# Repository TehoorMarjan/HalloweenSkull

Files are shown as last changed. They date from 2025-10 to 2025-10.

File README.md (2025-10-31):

# 🎃 HalloweenSkull - Animated Skull with Googly Eyes 👁️

An ESP32-powered animated skull featuring expressive googly eyes using 8x8 LED matrices and spooky sound effects. Perfect for creating an immersive, interactive Halloween decoration that watches and talks to visitors!

<p align="center">
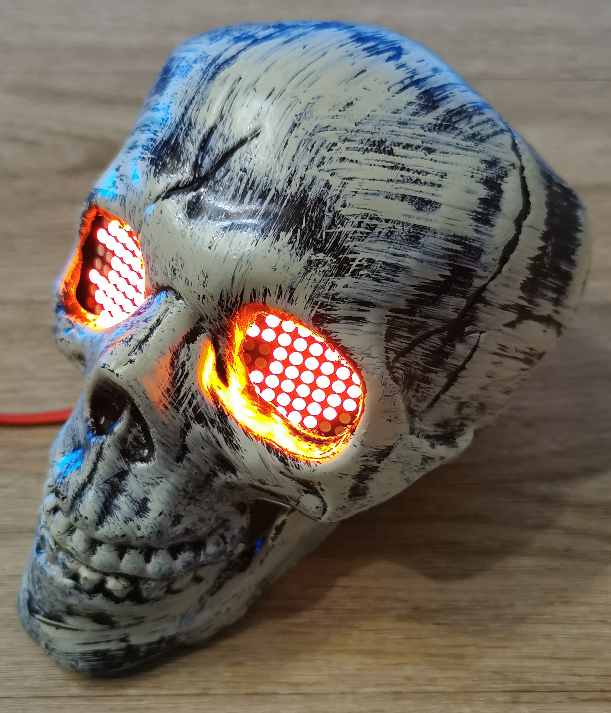
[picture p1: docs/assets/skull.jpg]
Skull Implementation
    
</p>

## 📖 Overview

**HalloweenSkull** brings a decorative skeleton to life with:
- 👀 **Animated LED matrix eyes** with smooth, realistic movements
- 🔊 **Sound effects** including spooky phrases, yawns, and atmospheric sounds
- 🤖 **Autonomous behavior** - the skull randomly looks around, blinks, and speaks
- 🛠️ **Custom 3D-printed mounts** to secure components inside the skull

The project combines hardware, firmware, and mechanical design to create an engaging Halloween decoration that captivates viewers.

👉 **See the README in each folder for detailed component documentation.**

## 🛠️ Hardware Requirements

### Components

- **ESP32 Development Board** (e.g., AZ-Delivery DevKit v4)
- **2x MAX7219 8x8 LED Dot Matrix Modules** (daisy-chained)
- **DFPlayer Mini MP3 Player Module** with microSD card
- **Speaker** (8Ω recommended, connected to DFPlayer)
- **MicroSD Card** (for audio files, FAT32 format)
- **Base Skull**: [5 Pcs Halloween Skeleton Head and Arm Set](https://www.amazon.fr/dp/B0FBW7PP8G)
- **3D Printed Mounts** (STL files in `mechanical/` folder)
- **Power Supply**: 5V, 2A+ recommended
- **Screws and basic hardware** for assembly

### Pin Connections

#### LED Matrices (SPI)
| ESP32 Pin | MAX7219 Pin | Description |
| --- | --- | --- |
| GPIO 18 | CLK | Clock signal |
| GPIO 23 | DIN | Data input (MOSI) |
| GPIO 5 | CS | Chip select |
| 5V | VCC | Power supply |
| GND | GND | Ground |

#### DFPlayer Mini (UART)
| ESP32 Pin | DFPlayer Pin | Description |
| --- | --- | --- |
| GPIO 17 | RX | ESP32 TX2 |
| GPIO 16 | TX | ESP32 RX2 |
| 5V | VCC | Power |
| GND | GND | Ground |

> 💡 The two MAX7219 modules are daisy-chained: Device 0 = Right eye, Device 1 = Left eye

## ✨ Features

### 👁️ Eye Animations
- **Googly eyes** with movable 2x2 pixel irises
- **Smooth interpolated movement** between positions
- **Multiple positions**: center, top, bottom, left, right, diagonals
- **Blinking/closing** animation with configurable probability
- **Adjustable brightness** (0-15)

### 🔊 Sound Effects
Three types of sounds played randomly:
- **Speech sounds** (folder 01) - Spooky phrases and words
- **Yawning sounds** (folder 02) - Triggered when eyes close
- **Effect sounds** (folder 03) - Atmospheric horror effects

Sounds are timed with configurable delays for unpredictable, natural behavior.

### 🎛️ Customization
All behavior is configurable via `firmware/src/config.h`:
- Animation timing and delays
- Eye brightness
- Sound volume and folder assignments
- Blink probability

## 🚀 Getting Started

### 1️⃣ Prepare the SD Card

1. Format a microSD card as **FAT32**
2. Copy the `sounds/` folder structure to the SD card root:
   ```
   SD Card Root/
   ├── 01/  (Speech sounds - 001.mp3, 002.mp3, ...)
   ├── 02/  (Yawning sounds)
   └── 03/  (Effect sounds - YOU MUST ADD THESE)
   ```
3. **Important**: The `03/` folder is empty by default due to licensing. Download your own sound effects from [Pixabay](https://pixabay.com/sound-effects/), [Freesound.org](https://freesound.org/), or similar sites.
4. Name files as `001.mp3`, `002.mp3`, etc. in MP3 format
5. Update `firmware/src/config.h` to match the number of files you added:
   ```cpp
   #define DFPLAYER_CONFIG { \
       .effectNbSounds = 6  // Change this to your file count
   }
   ```

### 2️⃣ 3D Print the Mounts

1. Open `mechanical/Mounts.FCStd` in FreeCAD, or use the exported STL files
2. Print the 3 parts:
   - **SupportLED**: Holds the two LED matrices
   - **HolderTop**: Upper arm part, screws to the skull
   - **HolderBottom**: Lower arm part, screws to SupportLED
3. See [`mechanical/README.md`](mechanical/README.md) for assembly details

### 3️⃣ Build and Upload Firmware

1. **Install PlatformIO** (VS Code extension recommended)
2. **Clone the repository**:
   ```bash
   git clone https://github.com/TehoorMarjan/HalloweenSkull.git
   cd HalloweenSkull/firmware
   ```
3. **Configure** (optional): Edit `src/config.h` for pin changes or customization
4. **Build and upload**:
   ```bash
   pio run --target upload
   ```
5. **Monitor** (optional):
   ```bash
   pio device monitor
   ```

See [`firmware/README.md`](firmware/README.md) for detailed firmware documentation.

### 4️⃣ Hardware Assembly

1. **Mount LED matrices** to the SupportLED using screws
2. **Attach the holder arms** creating an adjustable articulation
3. **Position inside skull**: Screw HolderTop inside the skull's "mouth"
4. **Connect electronics**: Wire ESP32 to LED matrices and DFPlayer
5. **Insert SD card** into DFPlayer Mini
6. **Power up** and test!
7. **Adjust positioning** using the articulated holder
8. **Close the skull** and enjoy your creation!

## 🐛 Troubleshooting

**Eyes don't light up:**
- Check SPI wiring (CLK, DATA, CS pins)
- Verify hardware type matches your LED modules
- Try increasing brightness in firmware config

**No sound:**
- Ensure SD card is FAT32 formatted
- Check UART connections (RX/TX are crossed!)
- Verify audio files follow naming convention (001.mp3, 002.mp3...)
- Update sound file count in firmware config to match your files

**Erratic behavior:**
- Use adequate power supply (2A+ recommended)
- Check all ground connections

> 💡 **See component-specific READMEs for detailed troubleshooting and configuration.**

## 🎨 Customization Ideas

- Add motion sensor to trigger reactions when people approach
- Implement WiFi control for remote triggering
- Add more eye animation modes (cross-eyed, silly)
- Synchronize with other Halloween props
- Add LED strip lighting effects
- Create themed sound sequences for different scenarios

## 📚 Documentation

- **[Firmware README](firmware/README.md)** - Detailed firmware documentation, API reference
- **[Mechanical README](mechanical/README.md)** - 3D models, assembly instructions, photos
- **[Sound Effects Guide](sounds/03/README)** - How to find and prepare audio files

## 🤝 Contributing

Contributions are welcome! Feel free to:
- 🐛 Report bugs via GitHub issues
- 💡 Suggest new features or improvements
- 🔧 Submit pull requests
- 📸 Share photos of your build
- 🎵 Contribute sound effect recommendations

Please ensure your code follows the existing style and includes appropriate documentation.

## � License

This project is licensed under the MIT License - see the [LICENSE](LICENSE) file for details.

### Third-Party Content

- **MAX7219 LED Matrix 3D Model**: By FabroLabs Technologies ([GrabCAD](https://grabcad.com/library/max7219-8x8-led-dot-matrix-display-module-1))
- **Sound Effects**: Not included - users must provide their own from free sources like Pixabay, Freesound.org, etc.

## 🙏 Acknowledgments

- MD_MAX72XX library by MajicDesigns
- DFRobotDFPlayerMini library
- PlatformIO and Arduino communities
- All the amazing free sound effect libraries

## 💀 Happy Halloween! 🎃👻

---

*Built with ❤️ for Halloween 2025 - May your decorations be spooky and your code bug-free!*

**⭐ If you build this project, please star the repo and share photos of your creation!**

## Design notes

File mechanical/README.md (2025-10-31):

# 🎃 HalloweenSkull Mechanical Components 🦴

Welcome to the mechanical folder for the **HalloweenSkull** project! Here you'll
find all the 3D models, CAD files, and documentation needed to build and
customize the mechanical parts of your animated skull.

## 🛠️ Mounts

- **File:** `Mounts.FCStd`
- **Description:** FreeCAD design for the mounts. The mount is split into 3
  bodies for easier print, assembly, and tweaking:
  - **SupportLED:** Holds the two LED matrices (with MAX7219 boards), which are
    screwed onto it.
  - **Holder (2 parts):** A two-part arm linking the support to the plastic
    skull. One part is screwed inside the skull's "mouth", the other to the
    support. The articulation between them allows for position adjustment within
    the skull.

<div align="center">
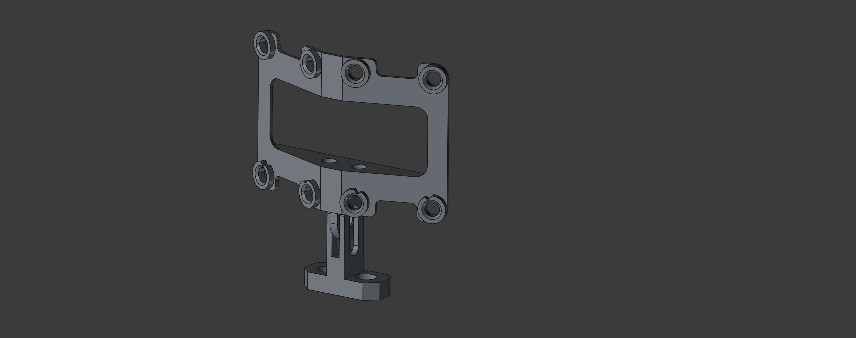
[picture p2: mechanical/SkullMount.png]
Mounts 3D Model
	
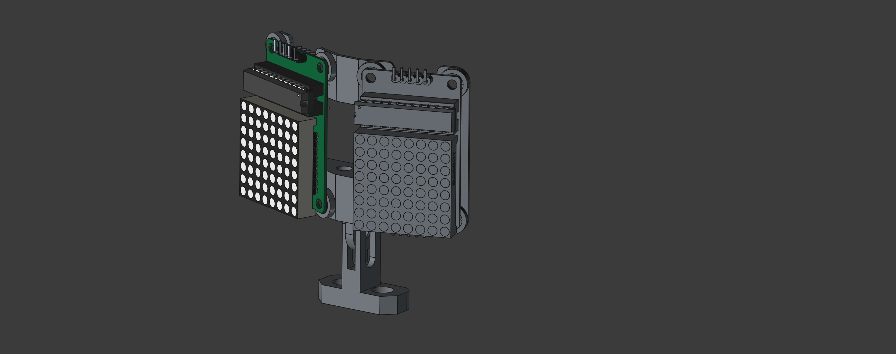
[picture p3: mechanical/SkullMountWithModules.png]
Mounts with Modules
	
</div>

## MAX7219 8x8 LED Dot Matrix Display Module

- **File:** `MAX7219 8x8 LED Dot Matrix Display Module.STEP`
- **Description:** 3D model of the LED matrix display used for the eyes.
- **License:** See
  [`MAX7219 8x8 LED Dot Matrix Display Module.STEP.LICENSE`](MAX7219%208x8%20LED%20Dot%20Matrix%20Display%20Module.STEP.LICENSE)
  for third-party info. Model by FabroLabs Technologies
  ([GrabCAD link](https://grabcad.com/library/max7219-8x8-led-dot-matrix-display-module-1)).

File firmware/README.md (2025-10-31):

# 👁️ HalloweenSkull Firmware 🎃

Welcome to the **HalloweenSkull** firmware! This is the embedded software that brings your animated skull to life with expressive googly eyes and spooky sounds.

## 🚀 Overview

This firmware is designed to run on an **ESP32** microcontroller and controls:
- **Two 8x8 LED matrices** (MAX7219-based) for animated googly eyes
- **DFPlayer Mini** audio module for playing sounds from an SD card

The skull autonomously animates its eyes with realistic movements and randomly plays sounds to create an immersive Halloween experience.

## 🛠️ Hardware Requirements

- **ESP32 Development Board** (e.g., AZ-Delivery DevKit v4)
- **2x MAX7219 8x8 LED Dot Matrix Modules** (daisy-chained)
- **DFPlayer Mini MP3 Player Module**
- **MicroSD Card** (for audio files)
- **Speaker** (connected to DFPlayer Mini)
- **Power Supply** (5V recommended)

### 📌 Pin Connections

#### LED Matrices (SPI)
- **CLK** → GPIO 18
- **DATA (MOSI)** → GPIO 23
- **CS** → GPIO 5

#### DFPlayer Mini (UART)
- **RX** (ESP32 TX2) → GPIO 17
- **TX** (ESP32 RX2) → GPIO 16

> You can modify pin assignments in `src/config.h`

## 📁 Project Structure

```
firmware/
├── platformio.ini          # PlatformIO configuration
├── src/
│   ├── main.cpp           # Main program logic
│   └── config.h           # Configuration constants
└── lib/
    ├── Eyes/              # Eye animation library
    │   ├── Eyes.h
    │   └── Eyes.cpp
    └── Sounds/            # Sound playback library
        ├── Sounds.h
        └── Sounds.cpp
```

## 🎨 Features

### Eye Animations
- **Smooth movement** between positions (top, bottom, left, right, center, diagonals)
- **Blinking/closing** animation with configurable probability
- **Interpolation** for natural eye movement
- **Adjustable brightness** (0-15)

### Sound Effects
The firmware plays three types of sounds from the SD card:
- **Yawning sounds** (folder 02) - triggered when eyes close
- **Speech sounds** (folder 01) - random spooky phrases
- **Effect sounds** (folder 03) - atmospheric effects

Sounds are played randomly with configurable delays to keep the experience unpredictable.

## 🔧 Building & Uploading

### Prerequisites
1. Install [PlatformIO](https://platformio.org/install) (VS Code extension recommended)
2. Prepare your SD card with sound files organized in folders:
   - `01/` - Speech sounds (001.mp3, 002.mp3, ...)
   - `02/` - Yawning sounds
   - `03/` - Effect sounds

### Build Commands

```bash
# Build the project
pio run

# Upload to ESP32
pio run --target upload

# Open serial monitor
pio device monitor
```

Or use the PlatformIO buttons in VS Code! 🔘

## 🎃 Customization Ideas

- Add new eye modes (cross-eyed, silly animations)
- Implement motion sensor triggers
- Add remote control via WiFi/Bluetooth
- Create synchronized light effects
- Add more complex sound sequences

## 📜 License

This project is part of the HalloweenSkull repository.

License is MIT. See the main [LICENSE](../LICENSE) file for details.

## 🤝 Contributing

Contributions are welcome! Feel free to:
- Report bugs via GitHub issues
- Submit pull requests with improvements
- Share your customizations and modifications

## 💀 Happy Haunting! 👻

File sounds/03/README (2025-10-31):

# Sound Effects - Folder 03

## ⚠️ Licensing Notice

The sound effects in this folder are sourced from **Pixabay** and are subject to
their content license terms. Due to licensing restrictions, these audio files
**cannot be redistributed** as part of this repository.

## 🎵 For Your Own Use

If you're building this project yourself, you are **free to download and use**
sound effects from Pixabay or other free sound libraries for your personal
Halloween skull project.

### Recommended Free Sound Libraries

1. **[Pixabay](https://pixabay.com/sound-effects/)** - Free for personal and
   commercial use

   - Search terms: "horror", "scary", "creepy", "halloween", "scream", "laugh"

2. **[Freesound.org](https://freesound.org/)** - CC-licensed sound effects

   - Requires attribution for some sounds

3. **[Zapsplat](https://www.zapsplat.com/)** - Free with attribution

   - Large collection of horror/Halloween sounds

4. **[BBC Sound Effects](https://sound-effects.bbcrewind.co.uk/)** - Free for
   personal use
   - High-quality professional recordings

### File Naming Convention

Files must follow the DFPlayer Mini naming convention:

```
03/
├── 001.mp3  (e.g., evil laugh)
├── 002.mp3  (e.g., scream)
├── 003.mp3  (e.g., creepy whisper)
└── 004.mp3  (e.g., chains rattling)
```

**Format Requirements:**

- MP3 or WAV format
- Sample rate: 16kHz-48kHz recommended
- Bitrate: up to 320kbps
- Files numbered with 3 digits (001, 002, 003, etc.)

### Tips for Best Results

- Keep files short (2-10 seconds) for quick impact
- Normalize volume levels across all files
- Test on your actual speaker to ensure clarity
- Consider your skull's acoustic properties (muffled vs. clear)

---

**Note**: Always respect content licenses and terms of use when downloading
sound effects. If unsure, use content explicitly marked as "Public Domain" or
"CC0".

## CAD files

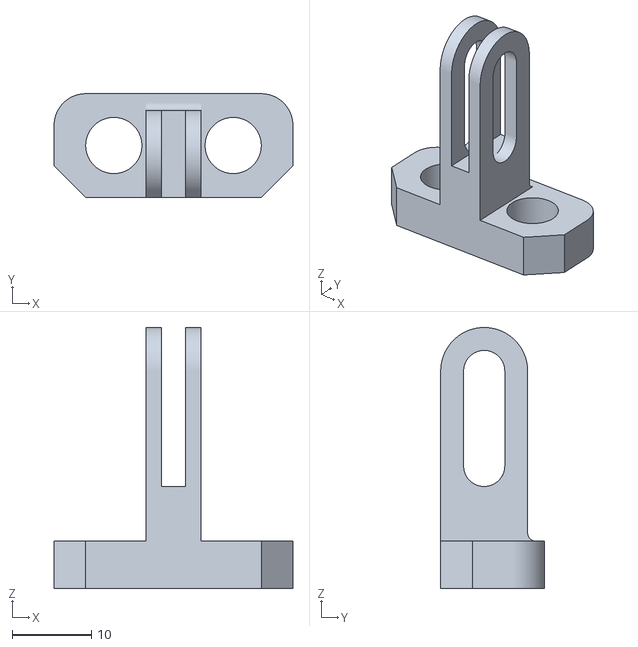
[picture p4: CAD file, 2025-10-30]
mechanical/Mounts-HolderBottom.stl
30.2 x 13.1 x 33.0

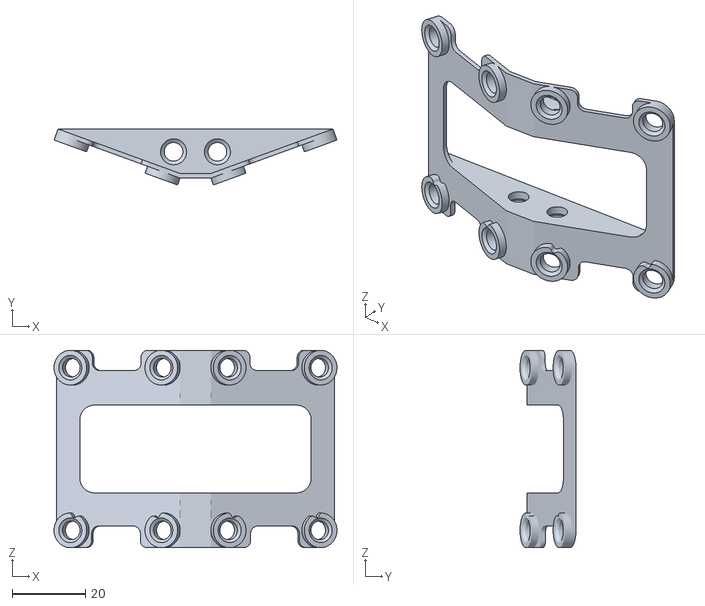
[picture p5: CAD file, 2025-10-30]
mechanical/Mounts-SupportLED.stl
77.4 x 15.3 x 54.0

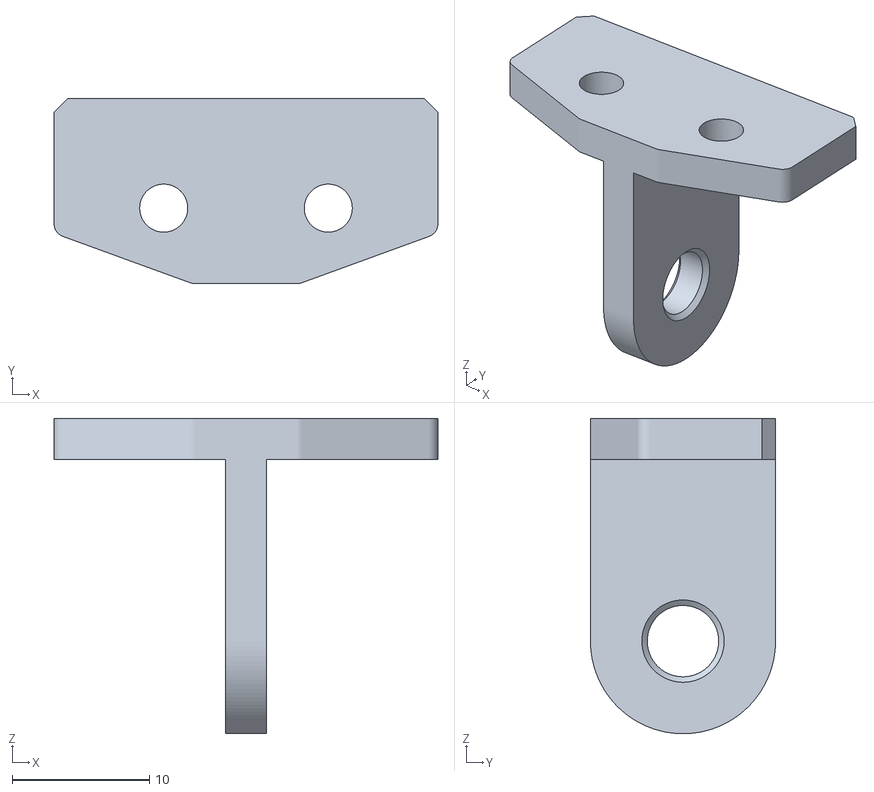
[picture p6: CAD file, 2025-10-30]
mechanical/Mounts-HolderTop.stl
28.0 x 13.5 x 23.0

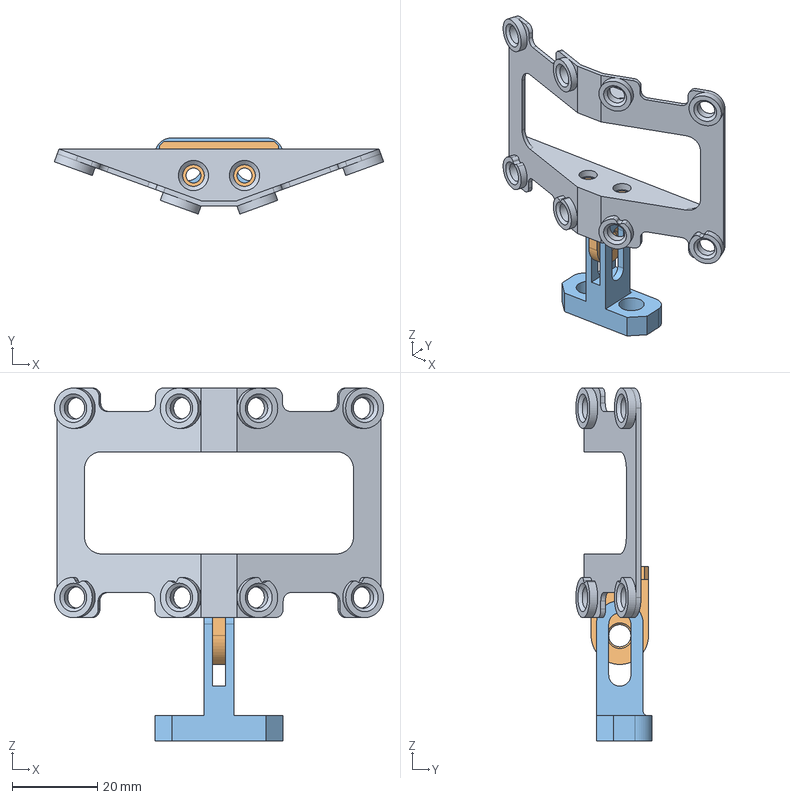
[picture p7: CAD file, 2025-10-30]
mechanical/Mounts.FCStd
77.4 x 17.9 x 83.0 mm
SupportLED
HolderTop
HolderBottom

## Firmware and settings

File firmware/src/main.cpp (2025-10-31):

#include <Arduino.h>
#include <esp_sleep.h>
#include <DFRobotDFPlayerMini.h>
#include <HardwareSerial.h>
#include <Eyes.h>
#include <Sounds.h>
#include "config.h"

void animateEyes();
void maybePlaySound(bool yawn = false);

static const SoundsConfig soundConfig = DFPLAYER_CONFIG;

// Create Eyes object
Eyes eyes(HARDWARE_TYPE, DATA_PIN, CLK_PIN, CS_PIN);

// Create DFPlayer object
Sounds sounds(DFPLAYER_RX, DFPLAYER_TX);

enum EyePosition
{
  TOP,
  BOTTOM,
  LEFT,
  RIGHT,
  CENTER,
  TOP_LEFT,
  TOP_RIGHT,
  BOTTOM_LEFT,
  BOTTOM_RIGHT,
  CENTER_LEFT,
  CENTER_RIGHT,
  TOP_CENTER,
  BOTTOM_CENTER,
};

typedef struct
{
  uint8_t x;
  uint8_t y;
} Position;

Position eyePositions[] = {
    {3, 6}, // TOP
    {3, 0}, // BOTTOM
    {0, 3}, // LEFT
    {6, 3}, // RIGHT
    {3, 3}, // CENTER
    {1, 5}, // TOP_LEFT
    {5, 5}, // TOP_RIGHT
    {1, 1}, // BOTTOM_LEFT
    {5, 1}, // BOTTOM_RIGHT
    {4, 3}, // CENTER_LEFT
    {2, 3}, // CENTER_RIGHT
    {3, 4}, // TOP_CENTER
    {3, 2}  // BOTTOM_CENTER
};

EyeMode currentMode = NORMAL;

unsigned long lastAnimationEndTime = 0;
unsigned long randomDelay = 0;

unsigned long lastSoundTime = 0;
unsigned long soundDelay = 0;

bool dfPlayerAvailable = false;

void setup()
{
  // Initialize serial communication
  Serial.begin(115200);
  
  // Initialize DFPlayer
  sounds.begin(soundConfig);
  
  // Initialize eyes
  eyes.begin();
  eyes.immediatePosition(3, 3); // Center
  eyes.setBrightness(EYES_BRIGHTNESS);
  eyes.immediateMode(CLOSED);
  eyes.requestMode(NORMAL); // Start with animation of opening eyes
}

void loop()
{
  animateEyes();
  maybePlaySound();
  delay(25);
  // Below breaks dfPlayer operation
  //esp_sleep_enable_timer_wakeup(25 * 1000); // 25ms in microseconds
  //esp_light_sleep_start();
}

void animateEyes()
{
  // Update the display
  eyes.update();

  if (eyes.isAnimating())
  {
    return; // Let animation finish
  }

  // Marker for end of animation, start of new delay
  if (lastAnimationEndTime == 0)
  {
    lastAnimationEndTime = millis();
    if (currentMode == CLOSED)
    {
      randomDelay = random(MIN_RANDOM_DELAY_CLOSED, MAX_RANDOM_DELAY_CLOSED);
    }
    else
    {
      randomDelay = random(MIN_RANDOM_DELAY, MAX_RANDOM_DELAY); // Initial random delay between 1 to 5 seconds
    }
  }

  // Wait until delay expires
  if (millis() - lastAnimationEndTime < randomDelay)
  {
    return; // Wait for delay to expire
  }

  // If we reach here, we can start a new animation
  lastAnimationEndTime = 0;

  // Decide next mode
  if (currentMode == CLOSED)
  {
    // If it was closed, open
    currentMode = NORMAL;
  }
  else
  {
    // Maybe close eyes, depending on probability
    int action = random(0, 100);
    if (action < CLOSED_MODE_PROBABILITY)
    {
      currentMode = CLOSED;
      maybePlaySound(true);
    }
  }
  eyes.requestMode(currentMode);

  if (currentMode == NORMAL)
  {
    // Pick a random position
    EyePosition pos = static_cast<EyePosition>(random(0, sizeof(eyePositions) / sizeof(eyePositions[0])));
    eyes.requestPosition(eyePositions[pos].x, eyePositions[pos].y);
  }
}

void maybePlaySound(bool yawn)
{
  unsigned long now = millis();
  if (now - lastSoundTime < soundDelay)
  {
    if (!yawn)
    {
      return; // Not time yet
    }
    else
    {
      // Allow yawns to proceed even if sound delay not yet passed
      // But only if minimum yawning interval has passed
      if (now - lastSoundTime < MIN_YAWNING_INTERVAL)
      {
        return; // Not enough time since last sound, cancel yawn
      }
    }
  }

  lastSoundTime = now;
  if (yawn)
  {
    sounds.playYawningSound();
  }
  else
  {
    sounds.playSpeechOrEffectSound();
  }

  soundDelay = random(MIN_SOUND_DELAY, MAX_SOUND_DELAY);
}

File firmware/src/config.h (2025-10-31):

#ifndef CONFIG_H
#define CONFIG_H

// Define hardware type (use GENERIC if unsure, or FC16_HW for common modules)
#define HARDWARE_TYPE MD_MAX72XX::FC16_HW
// Define SPI pins for ESP32
#define CLK_PIN 18  // Clock pin
#define DATA_PIN 23 // MOSI pin (Data In)
#define CS_PIN 5    // Chip Select pin

#define CLOSED_MODE_PROBABILITY 10 // Probability of entering CLOSED mode each update cycle (percent)

#define MIN_RANDOM_DELAY 1000 // Minimum random delay between animations (ms)
#define MAX_RANDOM_DELAY 5000 // Maximum random delay between animations (ms)

#define MIN_RANDOM_DELAY_CLOSED 3000 // Minimum random delay between CLOSED mode animations (ms)
#define MAX_RANDOM_DELAY_CLOSED 6000 // Maximum random delay between CLOSED mode animations (ms)

#define EYES_BRIGHTNESS 8 // Default display brightness (0-15)

// DFPlayer Mini configuration
#define DFPLAYER_RX 16  // ESP32 RX2 → DFPlayer TX
#define DFPLAYER_TX 17  // ESP32 TX2 → DFPlayer RX

#define DFPLAYER_CONFIG { \
    .volume = 30, \
    .yawningFolder = 2, \
    .speechFolder = 1, \
    .effectFolder = 3, \
    .yawningNbSounds = 3, \
    .speechNbSounds = 9, \
    .effectNbSounds = 6 \
}

#define MIN_SOUND_DELAY 20000 // Minimum delay between sounds (ms)
#define MAX_SOUND_DELAY 60000 // Maximum delay between sounds (ms)
#define MIN_YAWNING_INTERVAL 20000 // Yawning may come sooner than other sounds (ms)

#endif // CONFIG_H

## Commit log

2025-10-30 Base commit
    [Mounts-HolderBottom.stl, Mounts-HolderTop.stl, Mounts-SupportLED.stl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]
2025-10-30 Add sleep functionality to loop for reduced power consumption
